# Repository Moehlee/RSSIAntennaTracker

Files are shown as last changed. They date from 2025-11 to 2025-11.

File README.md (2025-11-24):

Open-Source Antenna Tracker

I added a non-commercial license, because i don't want that a company steals it

I did not Test it during flying, but i will share my experience

Parts list:
- ESP32F401CEU Blackpill 
- OWLRC Modul or any Fatshark module
- 2.54mm socket strip or 2x female servo cable
- 2x 13kg servo
- DC-DC Step Down Converter 4-40V 8A
  -> that powers the system
- DC-DC Step Down Converter 4-40V 3A
  -> just powers the module
- LCD 1602A
- 10k rotary potentiometer
- LED i found on the floor
- 220Ω Resistor
- Stlink i had the V2 
- XT60 female
- toggle switch
- buzzer
- 4-pin AUX cable
- m3 and m4 screws

Furthermore, you don't need exactly the same parts for it to work. My module uses RX5808 receivers, where the RSSI pin needs to be soldered on.

3D prints:
- https://www.thingiverse.com/thing:3500798/files
  - i used dock-front and fpv-module, the dock body i modified
- https://www.thingiverse.com/thing:1941574
- the case i made myself, they are on github

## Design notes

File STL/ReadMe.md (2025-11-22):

i used PETG for all of my prints, also used like 60% infill

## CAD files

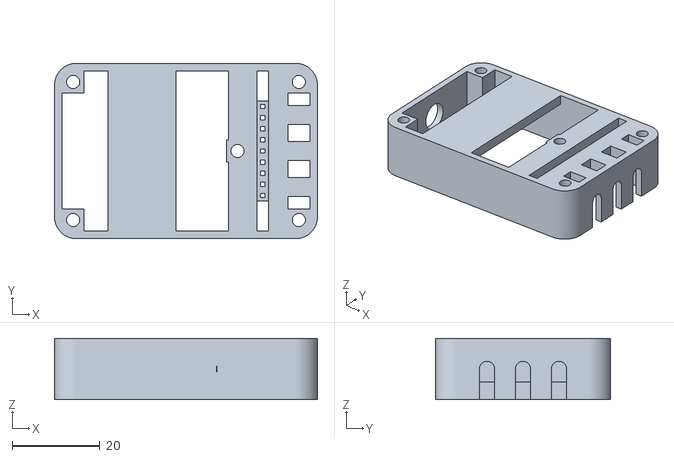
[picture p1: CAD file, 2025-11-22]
STL/fpv-module-dock-body.stl
60.0 x 40.0 x 14.0

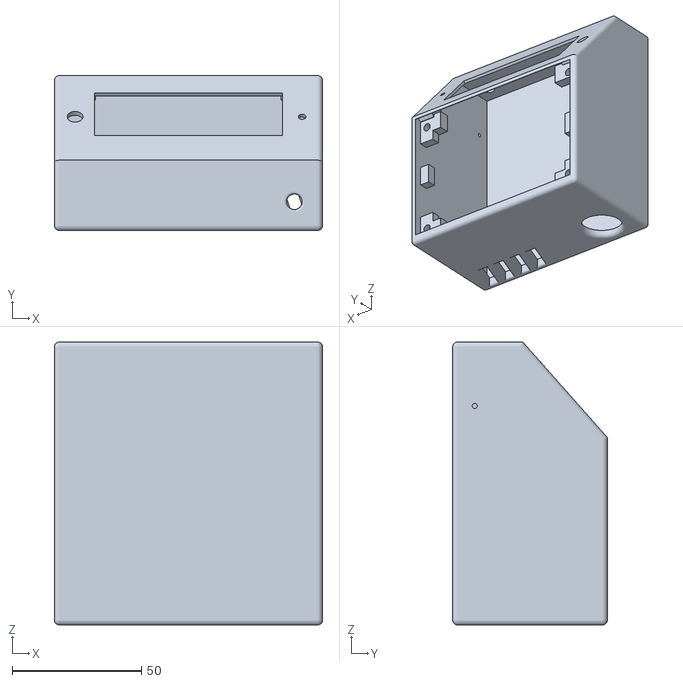
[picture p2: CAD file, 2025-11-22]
STL/AntennaTracker_housing.stl
104.0 x 60.0 x 109.7

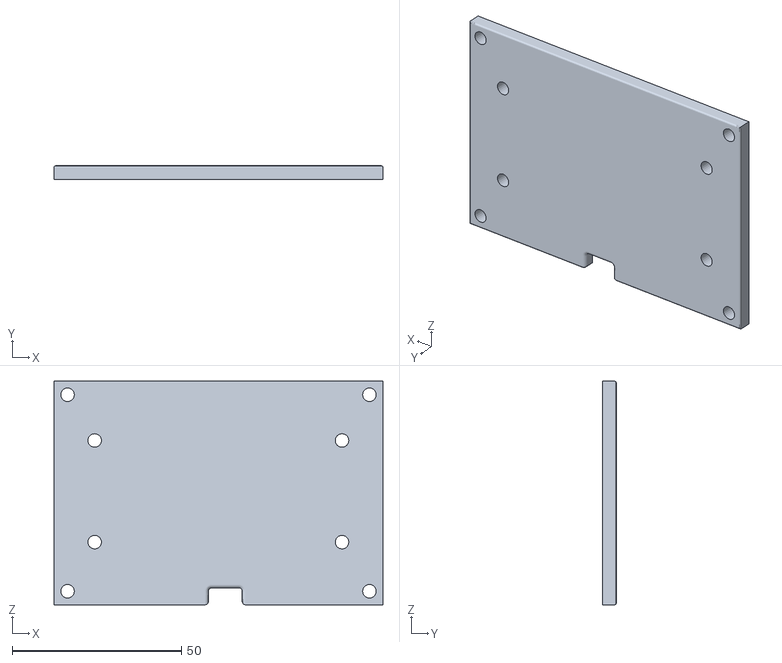
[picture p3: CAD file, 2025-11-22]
STL/AntennaTracker_lid.stl
97.1 x 4.00 x 66.0

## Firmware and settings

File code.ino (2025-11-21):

#include <Arduino.h>
#include <LiquidCrystal.h>
#include <Servo.h>

// PINS
constexpr uint8_t LCD_RS = A0;
constexpr uint8_t LCD_E = A1;
constexpr uint8_t LCD_D4 = A2;
constexpr uint8_t LCD_D5 = A3;
constexpr uint8_t LCD_D6 = A4;
constexpr uint8_t LCD_D7 = A5;

constexpr uint8_t ServoPanPin = PB8;
constexpr uint8_t ServoTiltPin = PB9;

constexpr uint8_t RSSI_ANT1_PIN = A6;
constexpr uint8_t RSSI_ANT2_PIN = A7;

constexpr uint8_t BUZZER_PIN = PA8;

#ifndef LED_BUILTIN
#define LED_BUILTIN PC13
#endif

Servo servoPan;
Servo servoTilt;
LiquidCrystal lcd(LCD_RS, LCD_E, LCD_D4, LCD_D5, LCD_D6, LCD_D7);

float panAngle  = 90.0;
float tiltAngle = 90.0;

float targetPan  = 90.0;
float targetTilt = 90.0;

#define RSSI_BUFFER_SIZE 5
int rssiBuffer[RSSI_BUFFER_SIZE] = {0};
int rssiIndex = 0;

bool tracking = false;

// Scan movement
int scanDir = 1;

const int SCAN_RANGE = 45;     // horizontal (PAN)
const int SCAN_STEP  = 2;      // etwas langsamer

const int SETTLE_TIME = 30;

const int RSSI_ON  = 320;
const int RSSI_OFF = 260;

const int PEAK_INTERVAL = 1300;   // Peak alle 1.3s

// Servo Limits
const int PAN_MIN  = 45;
const int PAN_MAX  = 135;
const int TILT_MIN = 85;       // leicht nach unten möglich
const int TILT_MAX = 130;      // nicht zu weit hoch

float KP = 0.16;
float KD = 0.05;

float lastPanError = 0;
float lastTiltError = 0;

unsigned long lastMove = 0;
unsigned long lastPeakSearch = 0;

int readRSSI() {
  int a1 = analogRead(RSSI_ANT1_PIN);
  int a2 = analogRead(RSSI_ANT2_PIN);
  return max(a1, a2);
}

int getFilteredRSSI(int raw) {
  rssiBuffer[rssiIndex] = raw;
  rssiIndex = (rssiIndex + 1) % RSSI_BUFFER_SIZE;

  int sum = 0;
  for (int i = 0; i < RSSI_BUFFER_SIZE; i++) sum += rssiBuffer[i];
  return sum / RSSI_BUFFER_SIZE;
}

void playSignalTone() {
  tone(BUZZER_PIN, 1000, 200); delay(250);
  tone(BUZZER_PIN, 1500, 200);
}

void playLostTone() {
  tone(BUZZER_PIN, 800, 300);
}

void moveServoSmooth(float &angle, float target, float &lastError, bool isTilt = false) {

  float error = target - angle;
  float derivative = error - lastError;

  float step = (KP * error + KD * derivative) * 0.30;  // WENIGER SPEED

  if (abs(error) > 1.0) angle += step;

  lastError = error;

  if (isTilt)
    angle = constrain(angle, TILT_MIN, TILT_MAX);
  else
    angle = constrain(angle, PAN_MIN, PAN_MAX);
}

int measureRSSIAtPan(float angle) {
  servoPan.write(angle);
  delay(120);
  return getFilteredRSSI(readRSSI());
}

int measureRSSIAtTilt(float angle) {
  servoTilt.write(angle);
  delay(120);
  return getFilteredRSSI(readRSSI());
}

void findBestPanPeak() {

  float center = panAngle;

  float left  = constrain(center - 8, PAN_MIN, PAN_MAX);
  float right = constrain(center + 8, PAN_MIN, PAN_MAX);

  int c = measureRSSIAtPan(center);
  int l = measureRSSIAtPan(left);
  int r = measureRSSIAtPan(right);

  if (l > c && l > r)      targetPan = left;
  else if (r > c)          targetPan = right;
  else                     targetPan = center;
}

void findBestTiltPeak() {

  float center = tiltAngle;

  float down = constrain(center - 6, TILT_MIN, TILT_MAX);
  float up   = constrain(center + 6, TILT_MIN, TILT_MAX);

  int c = measureRSSIAtTilt(center);
  int d = measureRSSIAtTilt(down);
  int u = measureRSSIAtTilt(up);

  if (d > c && d > u)      targetTilt = down;
  else if (u > c)          targetTilt = up;
  else                     targetTilt = center;
}

void setup() {

  pinMode(LED_BUILTIN, OUTPUT);
  pinMode(BUZZER_PIN, OUTPUT);

  servoPan.attach(ServoPanPin);
  servoTilt.attach(ServoTiltPin);

  servoPan.write(panAngle);
  servoTilt.write(tiltAngle);

  lcd.begin(16, 2);
  lcd.print("Antenna Tracker");
  delay(1000);
  lcd.clear();

  lastMove = millis();
  lastPeakSearch = millis();
}

void loop() {

  int rawRSSI = readRSSI();
  int rssi = getFilteredRSSI(rawRSSI);

  if (millis() - lastMove > SETTLE_TIME) {

    if (tracking) {

      if (rssi < RSSI_OFF) {
        tracking = false;
        playLostTone();
      } else {
        if (rssi < RSSI_ON + 20){
          targetTilt = 90;
        }

        if (millis() - lastPeakSearch > PEAK_INTERVAL) {
          findBestPanPeak();
          findBestTiltPeak();
          lastPeakSearch = millis();
        }
      }

    } else {

      if (rssi > RSSI_ON) {
        tracking = true;
        playSignalTone();
      } else {
        targetPan += scanDir * SCAN_STEP;

        if (targetPan >= 90 + SCAN_RANGE) { scanDir = -1; targetPan = 90 + SCAN_RANGE; }
        if (targetPan <= 90 - SCAN_RANGE) { scanDir =  1; targetPan = 90 - SCAN_RANGE; }

        targetTilt = 90;
      }
    }

    lastMove = millis();
  }

  moveServoSmooth(panAngle,  targetPan,  lastPanError,  false);
  moveServoSmooth(tiltAngle, targetTilt, lastTiltError, true);

  servoPan.write(round(panAngle));
  servoTilt.write(round(tiltAngle));

  int displayRSSI = map(constrain(rssi, 150, 400), 150, 400, 0, 99);

  lcd.setCursor(0, 0);
  lcd.print("RSSI: ");
  lcd.print(displayRSSI);
  lcd.print("    ");

  lcd.setCursor(0, 1);
  lcd.print(tracking ? "TRACKING " : "SCANNING ");

  digitalWrite(LED_BUILTIN, tracking ? LOW : HIGH);

  delay(20);
}
